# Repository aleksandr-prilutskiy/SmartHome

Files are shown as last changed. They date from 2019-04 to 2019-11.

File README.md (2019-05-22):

# SmartHome-SensorLPG
Блок датчика бытового газа для "Умного дома"<br>
<br>
Функции устройства:<br>
1. Чтение показаний датчика углеводородных газов и отправка их брокеру MQTT<br>
2. Чтение показаний датчика температуры и влажности и отправка их брокеру MQTT<br>
3. Сигнализация о превышении критического уровня углеводородных газов<br>
4. Контроль и настройка устройства через web-интерфейс<br>
5. Сброс настроек устройства при удержании специальной кнопк<br>
<br>
В папке <strong>Case</strong> - файлы под печать для копруса устройства.<br>
<h1>Схема</h1>
Аппаратные средства:<br>
- Контроллер <strong><a href="https://wiki.wemos.cc/products:d1:d1_mini">WeMos Di mini</a></strong><br>
- Датчик углеводородных газов <strong>MQ-6</strong><br>
- Датчик температуры и влажности <strong>DHT11</strong><br>
<br>
Подключение <strong>WeMos Di mini</strong>:<br>
 pin D0 -> Reset Button<br>
 pin D1 -> Error LED (Red)<br>
 pin D2 -> Power LED (Green)<br>
 pin D3 -> WiFi LED (Blue)<br>
 pin D4 -> DHT11 (BuiltIn LED)<br>
 pin D5 -> Piezo buzzer<br>
 pin D6 -> NC<br>
 pin D7 -> NC<br>
 pin D8 -> NC<br>
 pin A0 -> MQ6<br>
<br>
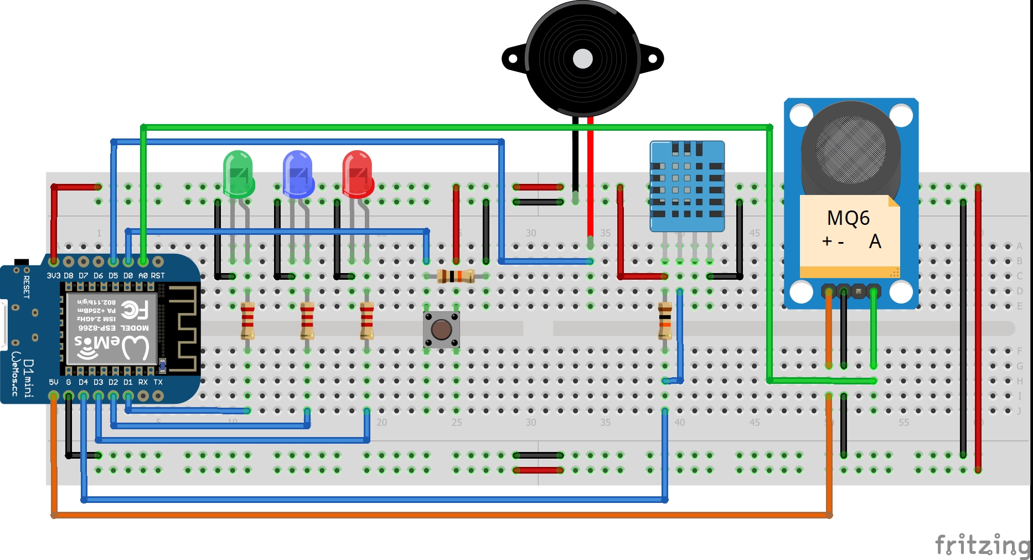
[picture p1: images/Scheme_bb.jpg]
<br>
Резисторы:<br>
- DHT11 и кнопrf = 10KOm<br>
- Светодиоды = 220Om..10KOm<br>
<br>
<h1>Инструкция</h1>
После прошивки контроллера должна появиться точка доступа "<strong>ESP8266WiFi</strong>", без пароля.<br>
Нужно подключиться к ней и зайти браузером по адресу <strong>192.168.0.1</strong><br>
Ввести имя точки доступа и пароль. После сохранения устройство будет перезагружено и попытается подключиться к сети.<br>
Если при включения устройства удерживать кнопку (она единственная), будут сброшены настройки и необходимо заново подключиться к точке доступа "<strong>ESP8266WiFi</strong>" и ввести настройки.<br>
Для работы датчиков необходимо иметь учетную запись брокера MQTT, например <a href="https://www.cloudmqtt.com/">https://www.cloudmqtt.com/</a>.
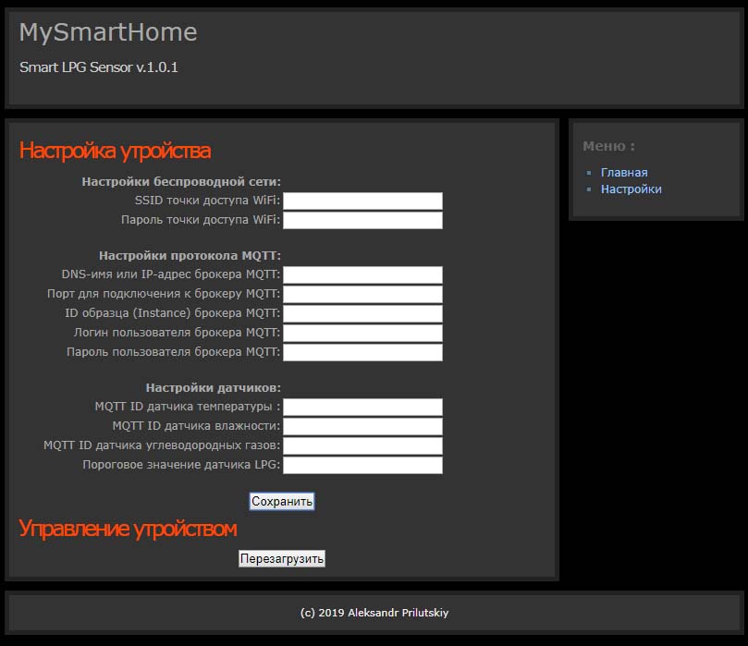
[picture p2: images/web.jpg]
<br>

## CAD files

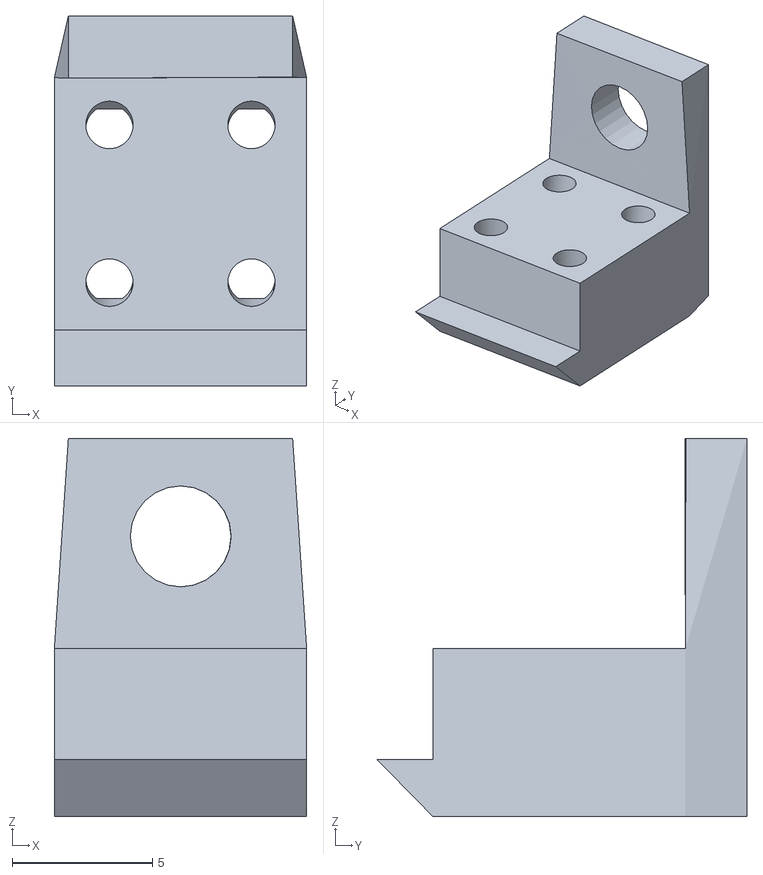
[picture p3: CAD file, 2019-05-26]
case/05-ButtonHolder.stl
9.00 x 13.2 x 13.5

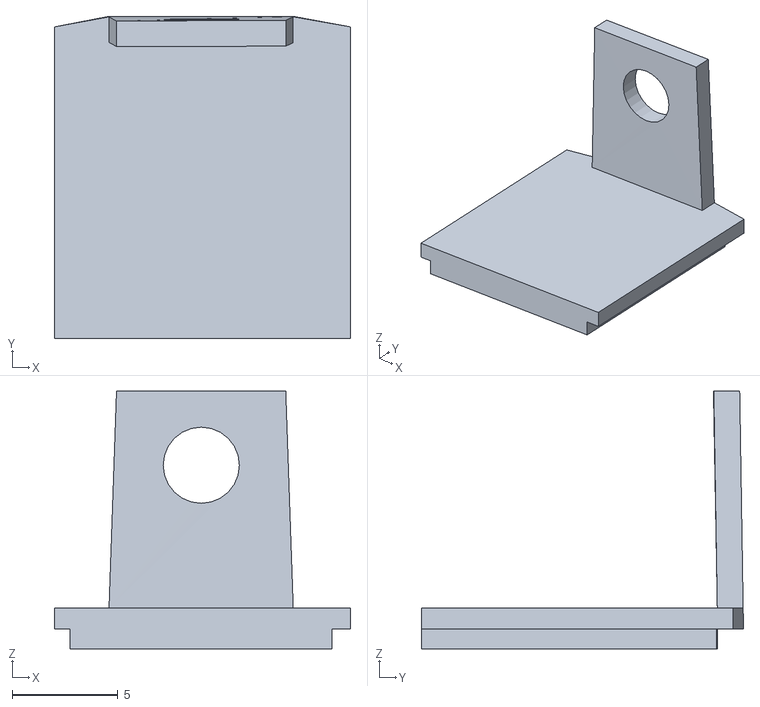
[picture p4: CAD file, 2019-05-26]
case/07-PlateDHT11.stl
14.0 x 15.2 x 12.2

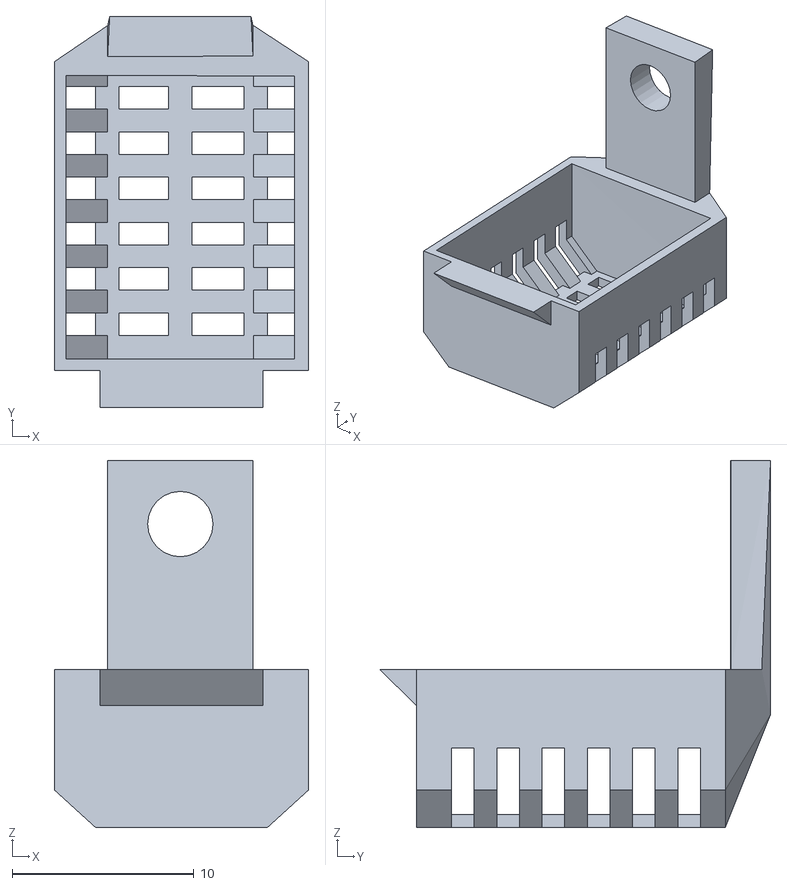
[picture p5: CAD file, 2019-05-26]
case/06-СoverDHT11.stl
14.0 x 21.5 x 20.2

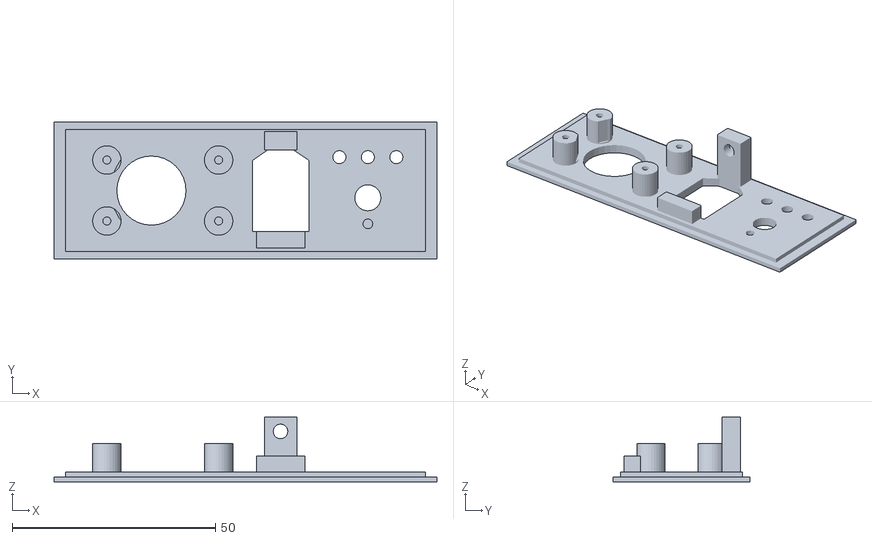
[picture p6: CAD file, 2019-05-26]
case/03-FrontPanel.stl
94.2 x 33.6 x 15.9

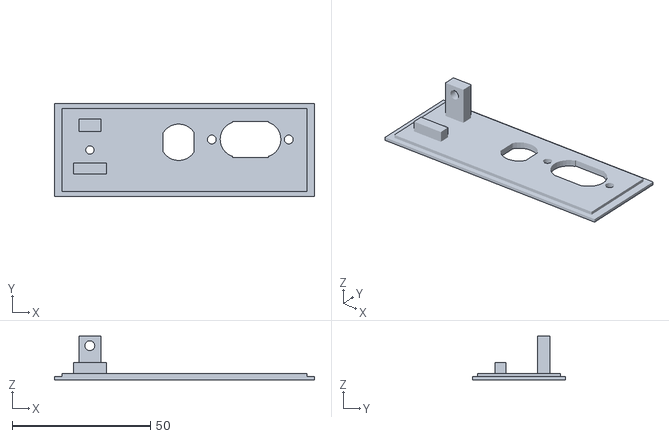
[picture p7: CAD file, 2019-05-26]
case/04-BackPanel.stl
94.2 x 33.6 x 15.9

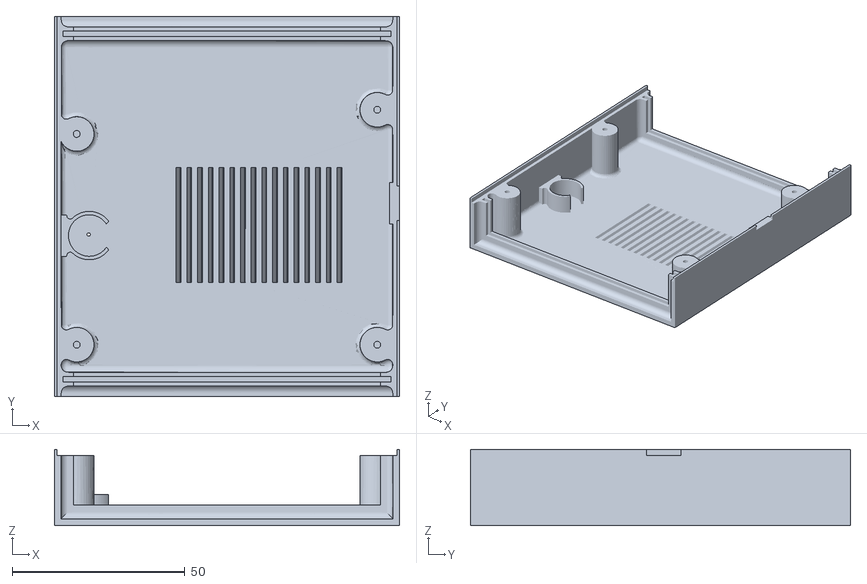
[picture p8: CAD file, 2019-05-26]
case/02-UpperShell.stl
100.0 x 110.0 x 22.1

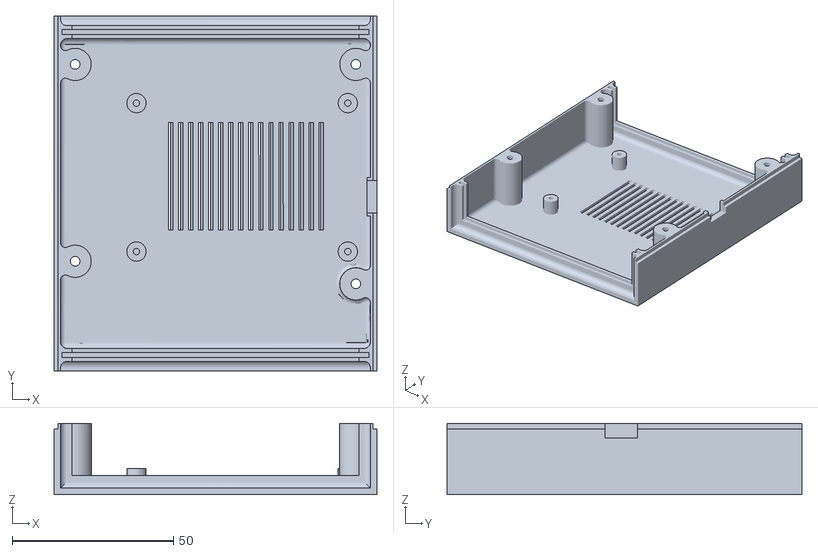
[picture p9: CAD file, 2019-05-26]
case/01-LowerShell.stl
100.0 x 110.0 x 22.1

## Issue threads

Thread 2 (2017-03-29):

29/03

aleksandr-prilutskiy, 2017-03-29:
#Region Initialization
#pragma compile(Out, ..\Install\Bin\MusicUpdate.exe)
#pragma compile(Icon, ..\Resources\Icons\Iconsmind-Outline-Hipster-Headphones.ico)
#pragma compile(ProductName, Smart Home Server - Music Database Update)
#pragma compile(FileVersion, 0.0.1.4)
#pragma compile(LegalCopyright, (c)2016 Aleksandr Prilutskiy)
#pragma compile(x64, false)
#pragma compile(UPX, false)
#pragma compile(Console, true)
#include <String.au3>
#include <Array.au3>
#include <Crypt.au3>
#include <FileConstants.au3>
#include <AutoItConstants.au3>
#include <..\UDFs\_MySQL.au3>
#include <..\UDFs\Encoding.au3>
#include <SmartHomeCommon.au3>
Opt("TrayIconHide", 1)

Global Enum _
 $_ID3_ATTR_FORMAT, _
 $_ID3_ATTR_TITLE, _
 $_ID3_ATTR_TRACK, _
 $_ID3_ATTR_YEAR, _
 $_ID3_ATTR_ALBUM, _
 $_ID3_ATTR_ARTIST, _
 $_ID3_ATTR_GENRE, _
 $_ID3_ATTR_SAMPLING, _
 $_ID3_ATTR_CHANNELS, _
 $_ID3_ATTR_BITDEPTH, _
 $_ID3_ATTR_DURATION, _
 $_ID3_ATTR_COUNT
Global Enum _
 $_Block_Type_STREAMINFO, _
 $_Block_Type_PADDING, _
 $_Block_Type_APPLICATION, _
 $_Block_Type_SEEKTABLE, _
 $_Block_Type_VORBIS_COMMENT, _
 $_Block_Type_CUESHEET
Global	$_Block_Type_MASK			= 0x7F
Global Enum _
 $_DB_ARTIST_ATTR_NAME, _
 $_DB_ARTIST_ATTR_ALBUMS, _
 $_DB_ARTIST_ATTR_TRACKS, _
 $_DB_ARTIST_ATTR_COUNT
Global Enum _
 $_DB_ALBUM_ATTR_NAME, _
 $_DB_ALBUM_ATTR_HASH, _
 $_DB_ALBUM_ATTR_ARTIST, _
 $_DB_ALBUM_ATTR_DIR, _
 $_DB_ALBUM_ATTR_TRACKS, _
 $_DB_ALBUM_ATTR_COUNT

Global	$sAppName				= $sProjectName & '. Music Database Update' ; наименование программы
Global	$sServerAddr			= ""									; IP-адрес DLNA-сервера
Global	$sPortDLNA				= ""									; TCP-порт DLNA-сервера
Global	$sWebServerDir			= ""									; каталог размещения web-ресурсов сервера
Global	$sAlbumsIconsDir		= "images\music\"						; каталог изображений с обложками альбомов
	    $iSQL_DebugMode			= $_DEBUG_MODE_ALL						; уровнь протоколирования работы с СУБД
Global	$ErrorCount				= 0										; счетчик ошибок
Global	$Count					= 0										; счетчик найденных файлов
Dim		$aDirs[1]				= [0]
Dim		$aArtists[1][$_DB_ARTIST_ATTR_COUNT] = [[0]]
Dim		$aAlbums[1][$_DB_ALBUM_ATTR_COUNT] = [[0]]
Global	$hFileOpen														; дискриптор обрабатываемого файла
Global	$DataBuffer														; буфер чтания обрабатываемого файла
Global	$iBufferSize			= 1024									; размер буфера чтения файла
Global	$iBufferPos				= 1										; маркер чтения данных в буфере чтения файла
Global	$sHashZerro				= "000000"								; нулевой идентификатор хэш-кода альбома
#EndRegion Initialization

#Region Main Script
$sExeFileName = @ScriptFullPath
If StringLower(StringRight($sExeFileName, 4)) <> '.exe' Then _
 $sExeFileName = @ScriptDir & '\..\Install\Bin\MusicUpdate.exe'
_LoadConfigFile()
$sLogFileName = $sServerAppDir & "\Logs\MusicUpdate.log"
_MySQL_Start()
_LogWrite($sAppName & " v." & $AppVersion & @CRLF)
_ReadServerConfig()				; чтение настроек системы "Умный дом"
_CreateMusicTables()			; создание в базе данных таблиц
_ScanMusicDirs()				; поиск в каталогах музыкальных файлов
_GetAllMusicIDs()				; получение всех идентификаторов объектов медиасервера
_CopyAllAlbumsIcons()			; копирование изображений обложек альбомов
_CheckErrors()
_Exit()
#EndRegion Main Script

#Region Read Config
; #FUNCTION# ====================================================================================================
; Name...........:	_ReadServerConfig
; Description....:	Чтение настроек системы "Умный дом" из базы данных
; Syntax.........:	_ReadServerConfig()
; ===============================================================================================================
Func _ReadServerConfig()
 Local $i, $Query, $sDir
 $Query = _MySQL_Query("SELECT data FROM `" & $sDB_TableConfig & "` WHERE name = 'ServerAddr';")
 If IsObj($Query) Then $sServerAddr = $Query.Fields(0).value
 $Query = _MySQL_Query("SELECT data FROM `" & $sDB_TableConfig & "` WHERE name = 'PortDLNA';")
 If IsObj($Query) Then $sPortDLNA = $Query.Fields(0).value
 $Query = _MySQL_Query("SELECT data FROM `" & $sDB_TableConfig & "` WHERE name = 'WebServerDir';")
 If IsObj($Query) Then $sWebServerDir = $Query.Fields(0).value
 If ($sServerAddr == "") OR ($sPortDLNA == "") OR ($sWebServerDir == "") Then
  _LogWrite("Ошибка получения параметров сервера из таблицы " & $sDB_TableConfig)
  _Exit()
 EndIf
 $Query = _MySQL_Query("SELECT data FROM `" & $sDB_TableConfig & "` WHERE name = 'MusicDir';")
 If IsObj($Query) Then
  While Not $Query.EOF
   $sDir = $Query.Fields(0).value
   If StringLen($sDir) > 0 Then
    $i = UBound($aDirs) + 1
    ReDim $aDirs[$i]
	$aDirs[$i - 1] = $sDir
	$aDirs[0] += 1
   EndIf
   $Query.MoveNext
  WEnd
 EndIf
EndFunc ;==>_ReadServerConfig
#EndRegion Read Config

#Region Create Tables
; #FUNCTION# ====================================================================================================
; Name...........:	_CreateMusicTables
; Description....:	Создание в базе данных таблиц с информацией о музыкальных треках, размещенных на сервере
; Syntax.........:	_CreateMusicTables()
; ===============================================================================================================
Func _CreateMusicTables()
 _LogWrite("Создание таблиц в базе данных:")
 _MySQL_DropTable($sDB_TableMusicArtists)
 _MySQL_Query("CREATE TABLE `" & $sDB_TableMusicArtists & "` (" & _
  "id SMALLINT UNSIGNED NOT NULL , " & _ 	; id исполнителя
  "artistname TEXT, " & _					; имя исполнителя
  "total_albums SMALLINT UNSIGNED, " & _	; кол-во альбомов исполнителя в коллекции
  "total_tracks SMALLINT UNSIGNED, " & _	; кол-во треков исполнителя в коллекции
  "PRIMARY KEY (`id`));")
 If Not @error Then
  _LogWrite("Создана таблица '" & $sDB_TableMusicArtists & "'")
 Else
  _LogWrite("Ошибка: Невозможно создать таблицу '" & $sDB_TableMusicArtists & "'")
 EndIf
 _MySQL_DropTable($sDB_TableMusicAlbums)
 _MySQL_Query("CREATE TABLE `" & $sDB_TableMusicAlbums & "` (" & _
  "id SMALLINT UNSIGNED NOT NULL, " & _ 	; id альбома
  "hash TEXT, " & _ 						; хэш-код альбома
  "albumname TEXT, " & _					; имя альбома
  "artist SMALLINT UNSIGNED, " & _ 			; id исполнителя
  "year SMALLINT UNSIGNED, " & _ 			; год выпуска альбома
  "genre TEXT, " & _ 						; стиль музыки (жанр)
  "dir TEXT, " & _ 							; каталог альбома на сервере
  "total_tracks SMALLINT UNSIGNED, " & _	; кол-во треков исполнителя в коллекции
  "PRIMARY KEY (`id`));")
 If Not @error Then
  _LogWrite("Создана таблица '" & $sDB_TableMusicAlbums & "'")
 Else
  _LogWrite("Ошибка: Невозможно создать таблицу '" & $sDB_TableMusicAlbums & "'")
 EndIf
 _MySQL_DropTable($sDB_TableMusicTracks)
 _MySQL_Query("CREATE TABLE `" & $sDB_TableMusicTracks & "` (" & _
  "id INT UNSIGNED NOT NULL AUTO_INCREMENT, " & _ ; id трэка
  "dlna_id TEXT NOT NULL, " & _				; id трэка в базе данных медиасервера
  "name TEXT, " & _							; имя трэка
  "track TINYINT UNSIGNED, " & _			; номер трэка в альбоме
  "album SMALLINT UNSIGNED, " & _ 			; id альбома
  "artist SMALLINT UNSIGNED, " & _ 			; id исполнителя
  "filename TEXT, " & _	 					; файл трэка на сервере
  "filesize INT UNSIGNED, " & _				; размер файла
  "filetype TEXT, " & _	 					; расширение (тип) файла
  "format TEXT, " & _	 					; формат файла
  "sampling INT UNSIGNED, " & _ 			; частота дискретизации файла
  "channels TINYINT UNSIGNED, " & _			; кол-во каналов
  "bitdepth TINYINT UNSIGNED, " & _			; кол-во бит на сэмпл
  "duration INT UNSIGNED, " & _				; длительность трэка (в секундах)
  "PRIMARY KEY (`id`));")
 If Not @error Then
  _LogWrite("Создана таблица '" & $sDB_TableMusicTracks & "'")
 Else
  _LogWrite("Ошибка: Невозможно создать таблицу '" & $sDB_TableMusicTracks & "'")
 EndIf
 _LogWrite("")
EndFunc ;==>_CreateMusicTables
#EndRegion Create Tables

#Region Scan Files Functions
; #FUNCTION# ====================================================================================================
; Name...........:	_ScanMusicDirs
; Description....:	Сканирование каталогов и поиск в них музыкальных файлов
; Syntax.........:	_ScanMusicDirs()
; Remarks .......:	Результат работы функции - частичное заполнение таблиц $sDB_TableMusicArtists,
;					$sDB_TableMusicAlbums и $sDB_TableMusicTracks в базе данных
;					Список каталогов берется из глобальной переменной-массива $aDirs
;					Первый элемент массива $aDirs содержит количество элементов в массиве и пропускется
; ===============================================================================================================
Func _ScanMusicDirs()
 Local $i, $Timer = TimerInit()
 $Count = 0
 For $i = 1 To UBound($aDirs) - 1
  _LogWrite("Сканирование каталога '" & $aDirs[$i] & "':")
  _ScanDir($aDirs[$i], ".mp3,.flac")
 Next
 For $i = 1 To UBound($aArtists, 1) - 1	; добавление сводной информации об исполнителях
  _MySQL_Query("UPDATE `" & $sDB_TableMusicArtists & "` " & _
   "SET total_albums = '" & $aArtists[$i][$_DB_ARTIST_ATTR_ALBUMS] & "', " & _
       "total_tracks = '"  & $aArtists[$i][$_DB_ARTIST_ATTR_TRACKS] & "' "& _
   "WHERE id = " & $i & ";")
 Next
 For $i = 1 To UBound($aAlbums, 1) - 1	; добавление сводной информации об альбомах
  _MySQL_Query("UPDATE `" & $sDB_TableMusicAlbums & "` " & _
   "SET total_tracks = '"  & $aAlbums[$i][$_DB_ALBUM_ATTR_TRACKS] & "' "& _
   "WHERE id = " & $i & ";")
 Next
 _LogWrite("Всего найдено файлов: " & $Count & @CRLF)
 Local $iCount = 0
 Local $Query = _MySQL_Query("SELECT COUNT(id) FROM `" & $sDB_TableMusicArtists & "`;")
 If IsObj($Query) Then $iCount = $Query.Fields(0).value
 _LogWrite("В таблицу '" & $sDB_TableMusicArtists & "' добавлено записей: " & $iCount)
 Local $iCount = 0
 Local $Query = _MySQL_Query("SELECT COUNT(id) FROM `" & $sDB_TableMusicAlbums & "`;")
 If IsObj($Query) Then $iCount = $Query.Fields(0).value
 _LogWrite("В таблицу '" & $sDB_TableMusicAlbums & "' добавлено записей: " & $iCount)
 Local $iCount = 0
 Local $Query = _MySQL_Query("SELECT COUNT(id) FROM `" & $sDB_TableMusicTracks & "`;")
 If IsObj($Query) Then $iCount = $Query.Fields(0).value
 _LogWrite("В таблицу '" & $sDB_TableMovies & "' добавлено записей: " & $iCount)
 _LogWrite("Затрачено времени: " & Round(TimerDiff($Timer) /  1000, 3) & " сек." & @CRLF)
EndFunc ;==>_ScanMusicDirs
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

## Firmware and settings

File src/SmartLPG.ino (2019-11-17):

//  Title:        SmartHome - Smart LPG Sensor
//  Filename:     SmartLPG.ino
//  Description:  Система "Умный дом". Скетч прошивки блока Smart LPG Sensor
//  Author:       Aleksandr Prilutskiy
//  Version:      0.0.6.0
//  Date:         08.11.2019
//  URL:          https://github.com/aleksandr-prilutskiy/SmartHome-SensorLPG
//
// Функции устройства:
// 1. Чтение показаний датчика углеводородных газов и отправка их брокеру MQTT
// 2. Чтение показаний датчика температуры и влажности и отправка их брокеру MQTT
// 3. Сигнализация о превышении критического уровня углеводородных газов
// 4. Контроль и настройка устройства через web-интерфейс
// 5. Сброс настроек устройства при удержании специальной кнопки
// 6. Ведение журнала работы устройства с синхронизацией времени по NTP
//
// Аппаратные средства:
//  WeMos Di mini (https://wiki.wemos.cc/products:d1:d1_mini)
//  Датчик углеводородных газов MQ-6
//  Датчик температуры и влажности DHT11
//
// Подключение:
//  pin D0 -> Reset Button
//  pin D1 -> Error LED (Red)
//  pin D2 -> Power LED (Green)
//  pin D3 -> WiFi LED (Blue)
//  pin D4 -> DHT11 (BuiltIn LED)
//  pin D5 -> Piezo buzzer
//  pin D6 -> NC
//  pin D7 -> NC
//  pin D8 -> NC
//  pin A0 -> MQ6

#include <ESP8266WiFi.h>
#include <ESP8266WebServer.h>
#include <PubSubClient.h>
#include <EEPROM.h> 
#include <DHT.h>

// Константы настройки устройства:
const String        deviceName       = "Smart LPG Sensor";   // Название устройства
const String        deviceVersion    = "6.0";                // Версия прошивки устройства
const uint8_t       pinButtonReset   = D0;                   // Кнопка сброса настроек WiFi
const uint8_t       ledError         = D1;                   // Светодиод индикации ошибки
const uint8_t       ledPower         = D2;                   // Светодиод индикации работы устройства
const uint8_t       ledWiFi          = D3;                   // Светодиод активности WiFi
const uint8_t       pinDHT           = D4;                   // Датчик DHT-11
const uint8_t       pinBuzzer        = D5;                   // Пьезоизлучатель
const uint8_t       pinMQ6           = A0;                   // Датчик углеводородных газов (MQ6)
const uint16_t      sizeEEPROM       = 512;                  // Размер используемой EEPROM

// Прочие переменные:
      String        errorStr         = "";                   // Строка с сообщением об ошибке
      bool          connectMQTT      = false;                // Признак подключения к брокеру MQTT
DHT                 dht11(pinDHT, DHT11);                    // Переменная для работы с датчиком DHT-11
ESP8266WebServer    WebServer(80);                           // Объект для работы с Web-сервером
WiFiClient          espClient;
PubSubClient        client(espClient);

// #FUNCTION# ===================================================================================================
// Name...........: setup
// Description....: Первоначальная настройка при запуске устройства
// Syntax.........: setup()
// ==============================================================================================================
void setup() {
 pinMode(ledError, OUTPUT);
 pinMode(ledPower, OUTPUT);
 pinMode(ledWiFi, OUTPUT);
 pinMode(pinBuzzer, OUTPUT);
 pinMode(pinButtonReset, INPUT);
 pinMode(pinMQ6, INPUT);
 digitalWrite(ledError, LOW);
 digitalWrite(ledPower, LOW);
 digitalWrite(ledWiFi, LOW);
 digitalWrite(pinBuzzer, LOW);
 Serial.begin(115200);
 Serial.println();
 Serial.println("Start...");
 CheckResetButton();
 logInit();
 dht11.begin();
 EEPROMReadAll();
 if (!WiFiCreateAP()) WiFiSetup();
 timeInit();
 WebServer.on("/",        webGetIndex);
 WebServer.on("/reset",   webGetReset);
 WebServer.on("/setup",   webGetSetup);
 WebServer.on("/log",     webGetLog);
 WebServer.on("/update",  webGetUpdate);
 WebServer.onNotFound(webNotFound);
 digitalWrite(ledPower, HIGH);
 tone(pinBuzzer, 415, 500);
 delay(650);
 tone(pinBuzzer, 466, 500);
 delay(650);
 tone(pinBuzzer, 370, 1000);
 digitalWrite(ledError, HIGH);
 digitalWrite(ledWiFi, HIGH);
 delay(1300);
 digitalWrite(ledError, LOW);
 digitalWrite(ledWiFi, LOW);
 noTone(pinBuzzer);
} // setup

// #FUNCTION# ===================================================================================================
// Name...........: loop
// Description....: Основной цикл работы устройства
// Syntax.........: loop()
// ==============================================================================================================
void loop() {
 delay(100);
 timeUpdate();
 WiFiReconnect();
 if ((WiFi.getMode() == WIFI_AP) || (WiFi.status() == WL_CONNECTED)) WebServer.handleClient();
 if (WiFi.getMode() != WIFI_STA) return;
 sensorsReadDHT11();
 sensorsReadLPG();
 if (WiFi.status() != WL_CONNECTED) return;
 sensorsCheckLPG();
 sensorsSendData();
} // loop

// #FUNCTION# ===================================================================================================
// Name...........: CheckResetButton
// Description....: Проверка нажатия кнопка сброса настроек и сброс настроек устройства при ее удержании
// Syntax.........: CheckResetButton()
// ==============================================================================================================
void CheckResetButton() {
 if (digitalRead(pinButtonReset) == LOW) return;
 uint32_t timer = millis() + 3000;
 while (millis() < timer) {
  delay(200);
  digitalWrite(ledPower, LOW);
  delay(200);
  digitalWrite(ledPower, HIGH);
  if (digitalRead(pinButtonReset) == LOW) return;
 }
 Serial.println();
 Serial.println("Reset device:");
 EEPROM.begin(sizeEEPROM);
 for (int i = 0; i < sizeEEPROM; i++) EEPROM.write(i, 0);
 EEPROM.commit();
 Serial.println("Clear EPPROM ... OK");
 Reboot();
} // CheckResetButton

// #FUNCTION# ===================================================================================================
// Name...........: Reboot
// Description....: Перезагрузка устройства
// Syntax.........: Reboot()
// ==============================================================================================================
void Reboot() {
 Serial.println("Reboot...");
 Serial.println();
 WiFi.disconnect(true);
 ESP.reset();
} // Reboot

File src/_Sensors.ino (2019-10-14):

//  Filename:     _Probes.ino
//  Description:  Система "Умный дом". Блок Smart LPG Sensor. Функции для работы с датчиками
//  Author:       Aleksandr Prilutskiy
//  Date:         06.09.2019

      float         lastTemperature  =      0;               // Текущее значение температуры
      float         sumTemperature   =      0;               // Накопление значений температуры
      float         lastHumidity     =      0;               // Текущее значение влажности
      float         sumHumidity      =      0;               // Накопление значений влажности
      uint16_t      countDHT11       =      0;               // Счетчик значений датчика температуры и влажности
const uint32_t      timeoutDHT11     =   5000;               // Периодичность проверки температуры и влажности
      uint32_t      timerDHT11       =      0;               // Таймер проверки датчика температуры и влажности

      float         lastLPG          =      0;               // Текущее значение углеводородных газов
      float         sumLPG           =      0;               // Накопление значений датчика углеводородных газов
      uint16_t      countLPG         =      0;               // Счетчик значений датчика углеводородных газов
const uint32_t      timeoutLPG       =  15000;               // Периодичность проверки углеводородных газов
      uint32_t      timerLPG         =      0;               // Таймер проверки датчика углеводородных газов
      bool          flagAlarmLPG     =  false;               // Признак превышения уровня углеводородных газов

const uint32_t      timeoutAlarmBeep =   3000;               // Период повторения сигнала углеводородных газов
      uint32_t      timerAlarmBeep   =      0;               // Таймер сигнализации уровня углеводородных газов
      uint32_t      timerSendData    =      0;               // Таймер отправки результатов измерений
const uint32_t      timeoutSendData  =  30000;               // Периодичность отправки результатов измерений

      char          msg[50];

// #FUNCTION# ===================================================================================================
// Name...........: sensorsReadDHT11
// Description....: Получение и накопление значений температуры и влажности от датчика DHT-11
// Syntax.........: sensorsReadDHT11()
// ==============================================================================================================
void sensorsReadDHT11() {
 if (((timerDHT11 == 0) && (millis() < 60000)) || (abs(millis() - timerDHT11) < timeoutDHT11)) return;
 digitalWrite(ledPower, LOW);
 timerDHT11 = millis();
 float temperature = dht11.readTemperature();
 float humidity = dht11.readHumidity();
 delay(500);
 if (isnan(temperature) || isnan(humidity)) {
  digitalWrite(ledPower, HIGH);
  Serial.println("Error: Sensor DHT11 Read Error");
  for (int i = 0; i < 3; i++) {
   digitalWrite(ledError, HIGH);
   delay(250);
   digitalWrite(ledError, LOW);
   delay(250);
  }
  return;
 }
 lastTemperature = round(10 * temperature) / 10;
 lastHumidity    = round(10 * humidity) / 10;
 sumTemperature  = sumTemperature +  temperature;
 sumHumidity     = sumHumidity + humidity;
 countDHT11++;
 Serial.println((String) "Temperature = " + lastTemperature + "C");
 Serial.println((String) "Humidity = " + lastHumidity + "%");
 digitalWrite(ledPower, HIGH);
} // sensorsReadDHT11

// #FUNCTION# ===================================================================================================
// Name...........: sensorsReadLPG
// Description....: Получение и накопление значений датчика углеводородных газов от датчика MQ6
// Syntax.........: sensorsReadLPG()
// ==============================================================================================================
void sensorsReadLPG() {
 if (abs(millis() - timerLPG) < timeoutLPG) return;
 digitalWrite(ledPower, LOW);
 timerLPG = millis();
 float gaz = 3.3 * analogRead(pinMQ6) / 5;
 delay(250);
 digitalWrite(ledPower, HIGH);
 delay(250);
 digitalWrite(ledPower, LOW);
 delay(250);
 if (gaz == 0) {
  digitalWrite(ledPower, HIGH);
  Serial.println("Error: Sensor LPG Read Error");
  for (int i = 0; i < 5; i++) {
   digitalWrite(ledError, HIGH);
   delay(250);
   digitalWrite(ledError, LOW);
   delay(250);
  }
  return;
 }
 lastLPG = round(10 * gaz) / 10;
 sumLPG  = sumLPG + gaz;
 countLPG++;
 Serial.println((String) "LPG = " + lastLPG + " PPM");
 digitalWrite(ledPower, HIGH);
} // sensorsReadLPG

// #FUNCTION# ===================================================================================================
// Name...........: sensorsCheckLPG
// Description....: Проверка значений датчика углеводородных газов. Отправка данных на сервер "Умного дома" и
//                  звуковой сигнал в случае превышения допустимого уровня
// Syntax.........: sensorsCheckLPG()
// ==============================================================================================================
void sensorsCheckLPG() {
 digitalWrite(ledError, LOW);
 if ((alarmLPG == 0) || (lastLPG < alarmLPG)) {
  flagAlarmLPG = false;
  return;
 }
 digitalWrite(ledError, HIGH);
 if (!flagAlarmLPG) logSave(logAlarmLPG, (int)lastLPG);
 flagAlarmLPG = true;
 if (abs(millis() - timerAlarmBeep) < timeoutAlarmBeep) return;
 timerAlarmBeep = millis();
 tone(pinBuzzer, 2500);
 Serial.print("WARNING! LPG = ");
 Serial.print(lastLPG);
 Serial.println(" PPM");
 if (!client.connected()) MQTTReconnect();
 if (!client.connected()) return;
 snprintf(msg, 50, "%f", lastLPG);
 client.publish(MQTT_LPG.c_str(), msg);
 digitalWrite(ledWiFi, LOW);
 while (abs(millis() - timerAlarmBeep) < 1000) delay(10); 
 noTone(pinBuzzer);
 timerAlarmBeep = millis();
} // sensorsCheckLPG
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
